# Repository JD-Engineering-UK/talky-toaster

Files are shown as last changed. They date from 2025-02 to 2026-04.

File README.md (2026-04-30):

# Talky-toaster

Inspired by the television show Red Dwarf.

This repository contains the firmware for a real-life version of the talky-toaster using a mmWave presence sensor, an audio amplifier and an ESP32S3 microcontroller.

## Features
- OTA update
- Time aware (NTP sync over WiFi)
- MP3 decompression and playback
- Motion sensor reading (including distance)

## TODO:
- [ ] Telemetry
- [ ] Configuration
- [ ] Silent OTA Update (Boot sounds play after OTA update but I don't want sounds playing out of hours)

## Possible Future Development:
- [ ] LED lights when the toaster is "speaking"
- [ ] Integrate more closely with a toaster. Possibly to detect how well-done the toast is or perhaps to simply have a voice line when the toaster lever is pressed down.
- [ ] Implement "wake word detection" to detect rejections of the toasters offers of grilled bread products and respond accordingly

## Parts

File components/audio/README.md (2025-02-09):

# Audio Driver
Simple audio driver to playback uncompressed PCM audio from read only memory

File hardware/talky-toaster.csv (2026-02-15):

Reference | Qty | Value | DNP | Exclude from BOM | Exclude from Board | Footprint | Datasheet
C1,C6 |  | 2 | 22uF |  |  |  | Capacitor_SMD:C_0603_1608Metric_Pad1.08x0.95mm_HandSolder | ~
C2,C3 |  | 2 | DNF | DNP |  |  | Capacitor_SMD:C_0402_1005Metric_Pad0.74x0.62mm_HandSolder | ~
C4 |  |  | 1 | 4.7uF |  |  |  | Capacitor_SMD:C_0603_1608Metric_Pad1.08x0.95mm_HandSolder | ~
C5 |  |  | 1 | 120pF | DNP |  |  | Capacitor_SMD:C_0402_1005Metric_Pad0.74x0.62mm_HandSolder | ~
C7,C8,C10 | 3 | 100nF |  |  |  | Capacitor_SMD:C_0402_1005Metric_Pad0.74x0.62mm_HandSolder | ~
C9 |  |  | 1 | 10uF |  |  |  | Capacitor_SMD:C_0603_1608Metric_Pad1.08x0.95mm_HandSolder | ~
D1,D2 |  | 2 | D_Schottky_Small |  |  |  | Diode_SMD:D_SOD-123 | ~
D3 |  |  | 1 | LED_ARGB |  |  |  | Auto Lib:19237R6GHBHCA012T | ~
J1 |  |  | 1 | UJ20-C-H-G-MSMT-4-P16-TR |  |  |  | Auto Lib:UJ20CHGMSMT4P16TR | https://www.sameskydevices.com/product/resource/supplyframepdf/uj20-c-h-g-msmt-4-p16-tr.pdf
J2 |  |  | 1 | Wj250A-3.5-2P |  |  |  | talky-toaster:Spring Terminal 2P
J3 |  |  | 1 | mmWave Sensor Socket |  |  |  | Connector_PinSocket_2.54mm:PinSocket_1x05_P2.54mm_Vertical | ~
L1 |  |  | 1 | 1uH |  |  |  | Inductor_SMD:L_1812_4532Metric_Pad1.30x3.40mm_HandSolder | ~
R1,R2 |  | 2 | 0R |  |  |  | Resistor_SMD:R_0402_1005Metric_Pad0.72x0.64mm_HandSolder | ~
R3 |  |  | 1 | 420k |  |  |  | Resistor_SMD:R_0402_1005Metric_Pad0.72x0.64mm_HandSolder | ~
R4 |  |  | 1 | 100k |  |  |  | Resistor_SMD:R_0402_1005Metric_Pad0.72x0.64mm_HandSolder | ~
R5 |  |  | 1 | 499k |  |  |  | Resistor_SMD:R_0402_1005Metric_Pad0.72x0.64mm_HandSolder | ~
R6,R7 |  | 2 | 5.1k |  |  |  | Resistor_SMD:R_0402_1005Metric_Pad0.72x0.64mm_HandSolder | ~
R8 |  |  | 1 | 10k |  |  |  | Resistor_SMD:R_0402_1005Metric_Pad0.72x0.64mm_HandSolder | ~
R9 |  |  | 1 | 560k |  |  |  | Resistor_SMD:R_0402_1005Metric_Pad0.72x0.64mm_HandSolder | ~
R10,R11,R12 | 3 | 2.2k |  |  |  | Resistor_SMD:R_0402_1005Metric_Pad0.72x0.64mm_HandSolder | ~
TP1,TP5 |  | 2 | TestPoint_2Pole |  |  |  | Connector_PinHeader_1.00mm:PinHeader_2x01_P1.00mm_Vertical_SMD | ~
TP2 |  |  | 1 | TestPoint_2Pole |  |  |  | Connector_PinSocket_2.54mm:PinSocket_2x01_P2.54mm_Vertical | ~
TP3,TP4 |  | 2 | TestPoint |  |  |  | TestPoint:TestPoint_Pad_D1.0mm | ~
U1 |  |  | 1 | ESP32-S3-WROOM-1 |  |  |  | RF_Module:ESP32-S3-WROOM-1 | https://www.espressif.com/sites/default/files/documentation/esp32-s3-wroom-1_wroom-1u_datasheet_en.pdf
U2 |  |  | 1 | TPS62A01DRL |  |  |  | Package_TO_SOT_SMD:SOT-563 | https://www.ti.com/lit/gpn/tps62a01
U3 |  |  | 1 | MAX98357A |  |  |  | Package_DFN_QFN:TQFN-16-1EP_3x3mm_P0.5mm_EP1.23x1.23mm_ThermalVias | https://www.analog.com/media/en/technical-documentation/data-sheets/MAX98357A-MAX98357B.pdf

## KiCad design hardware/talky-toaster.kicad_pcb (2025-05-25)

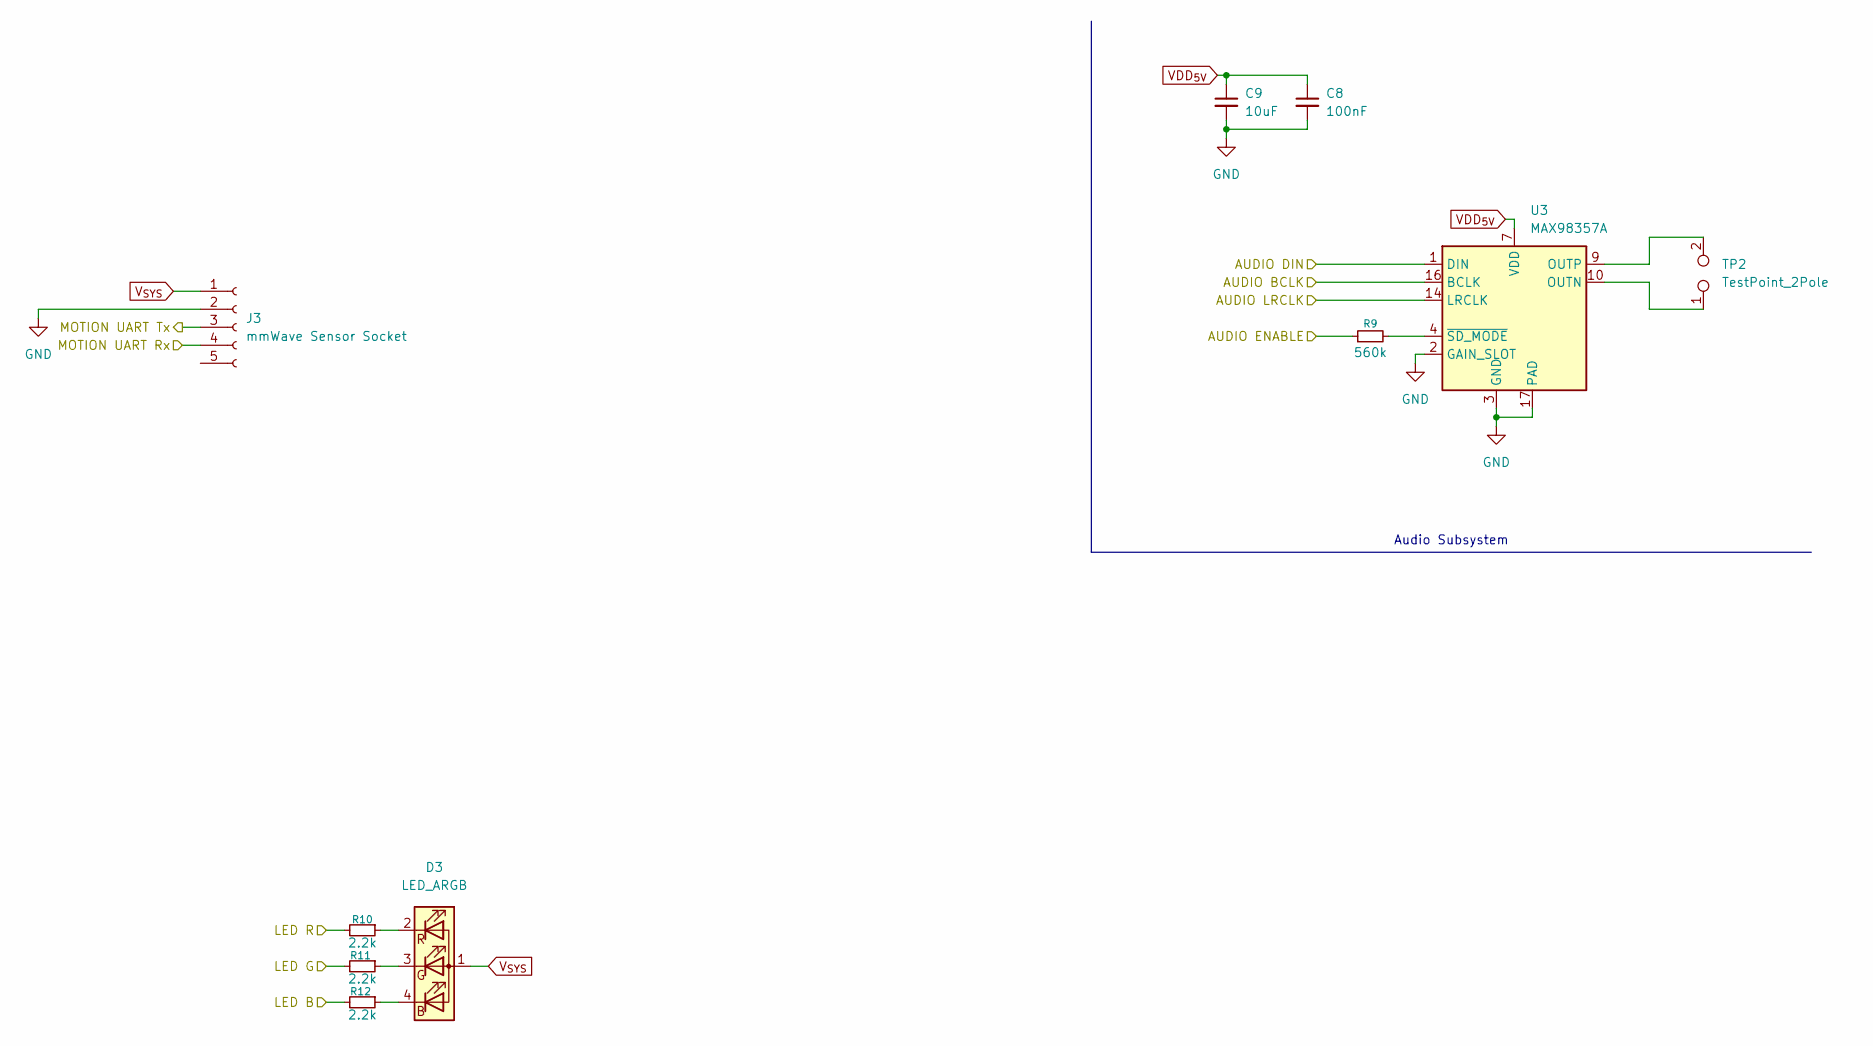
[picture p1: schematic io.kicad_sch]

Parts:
C8: 100nF; C_0402_1005Metric_Pad0.74x0.62mm_HandSolder
C9: 10uF; C_0603_1608Metric_Pad1.08x0.95mm_HandSolder
D3: LED_ARGB; 19237R6GHBHCA012T
J3: mmWave Sensor Socket; PinSocket_1x05_P2.54mm_Vertical
R9: 560k; R_0402_1005Metric_Pad0.72x0.64mm_HandSolder
R10, R11, R12: 2.2k; R_0402_1005Metric_Pad0.72x0.64mm_HandSolder
TP2: TestPoint_2Pole; PinSocket_2x01_P2.54mm_Vertical
U3: MAX98357A; TQFN-16-1EP_3x3mm_P0.5mm_EP1.23x1.23mm_ThermalVias

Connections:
/IO/AUDIO BCLK: U3.16 (BCLK); also elsewhere on the board
/IO/AUDIO DIN: U3.1 (DIN); also elsewhere on the board
/IO/AUDIO ENABLE: R9.1; also elsewhere on the board
/IO/AUDIO LRCLK: U3.14 (LRCLK); also elsewhere on the board
/IO/LED B: R12.2; also elsewhere on the board
/IO/LED G: R11.2; also elsewhere on the board
/IO/LED R: R10.2; also elsewhere on the board
/IO/MOTION UART Rx: J3.4; also elsewhere on the board
/IO/MOTION UART Tx: J3.3; also elsewhere on the board
GND: C8.2, C9.2, J3.2, U3.2 (GAIN_SLOT), U3.3 (GND), U3.11 (GND), U3.15 (GND), U3.17 (PAD); also elsewhere on the board
unnamed: D3.4 (BK), R12.1
unnamed: D3.3 (GK), R11.1
unnamed: D3.2 (RK), R10.1
unnamed: TP2.1, U3.10 (OUTN)
unnamed: TP2.2, U3.9 (OUTP)
unnamed: R9.2, U3.4 (~SD_MODE)
VDD_{5V}: C8.1, C9.1, U3.7 (VDD), U3.8 (VDD); also elsewhere on the board
V_{SYS}: D3.1 (A), J3.1; also elsewhere on the board

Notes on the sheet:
Audio Subsystem

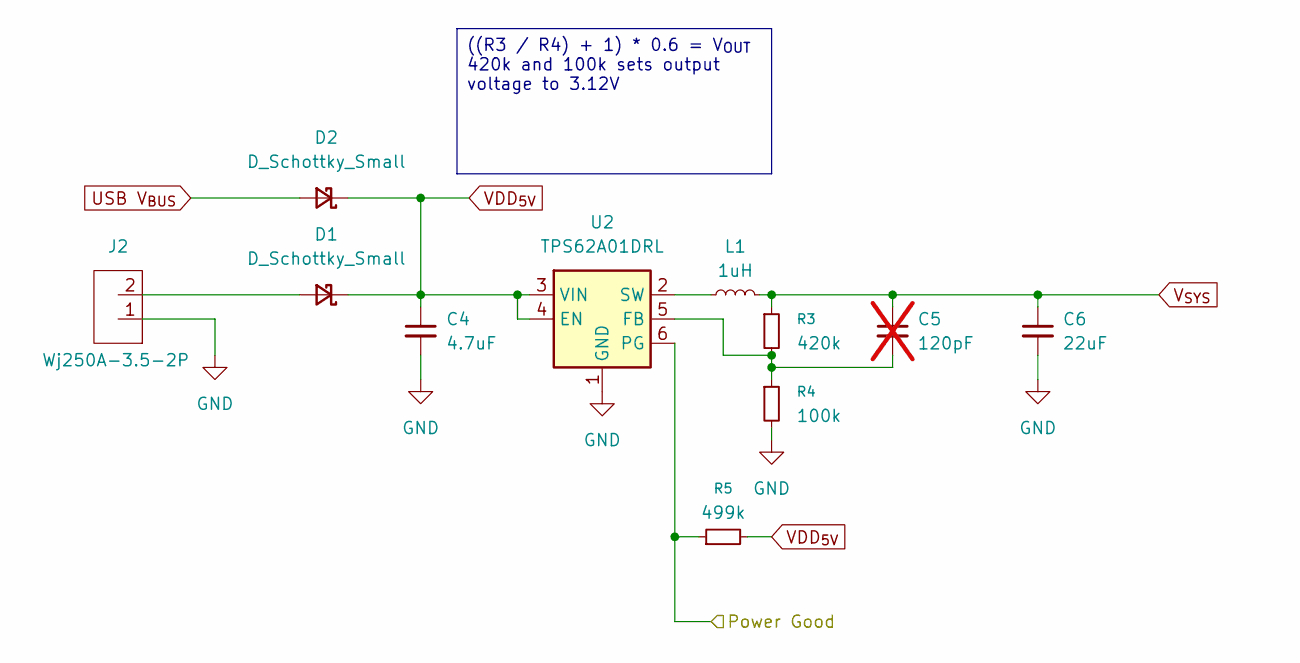
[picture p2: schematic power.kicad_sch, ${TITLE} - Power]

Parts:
C4: 4.7uF; C_0603_1608Metric_Pad1.08x0.95mm_HandSolder
C5: 120pF; C_0402_1005Metric_Pad0.74x0.62mm_HandSolder; not fitted
C6: 22uF; C_0603_1608Metric_Pad1.08x0.95mm_HandSolder
D1, D2: D_Schottky_Small; D_SOD-123
J2: Wj250A-3.5-2P; Spring Terminal 2P
L1: 1uH; L_1812_4532Metric_Pad1.30x3.40mm_HandSolder
R3: 420k; R_0402_1005Metric_Pad0.72x0.64mm_HandSolder
R4: 100k; R_0402_1005Metric_Pad0.72x0.64mm_HandSolder
R5: 499k; R_0402_1005Metric_Pad0.72x0.64mm_HandSolder
U2: TPS62A01DRL; SOT-563

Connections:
/MCU/Power Good: R5.1, U2.6 (PG); also elsewhere on the board
GND: C4.2, C6.2, J2.1, R4.2, U2.1 (GND); also elsewhere on the board
unnamed: D1.2 (A), J2.2
unnamed: C5.2, R3.2, R4.1, U2.5 (FB)
unnamed: L1.1, U2.2 (SW)
USB V_{BUS}: D2.2 (A); also elsewhere on the board
VDD_{5V}: C4.1, D1.1 (K), D2.1 (K), R5.2, U2.3 (VIN), U2.4 (EN); also elsewhere on the board
V_{SYS}: C5.1, C6.1, L1.2, R3.1; also elsewhere on the board

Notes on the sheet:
((R3 / R4) + 1) * 0.6 = V_{OUT} 420k and 100k sets output voltage to 3.12V

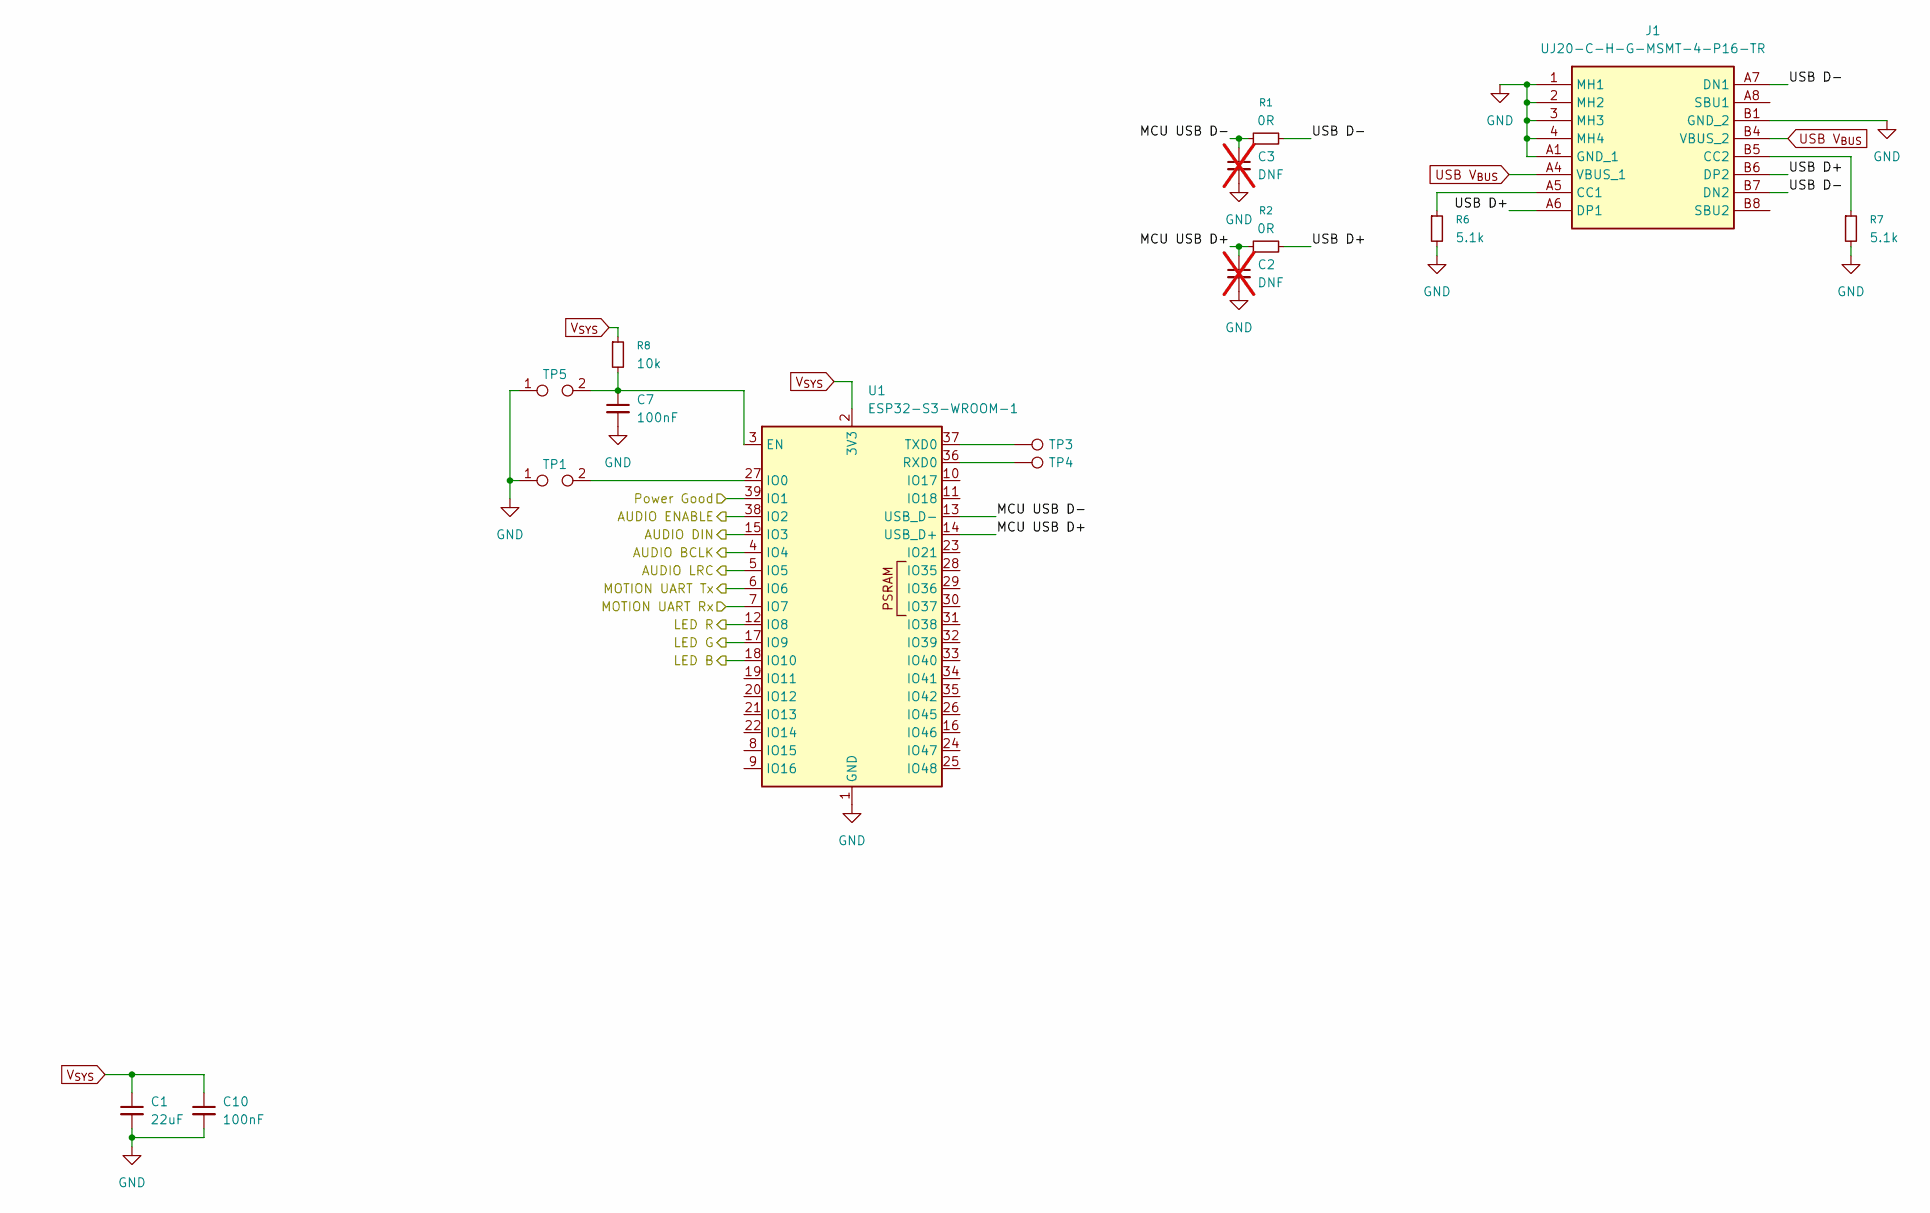
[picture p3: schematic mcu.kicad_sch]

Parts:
C1: 22uF; C_0603_1608Metric_Pad1.08x0.95mm_HandSolder
C2, C3: DNF; C_0402_1005Metric_Pad0.74x0.62mm_HandSolder; not fitted
C7, C10: 100nF; C_0402_1005Metric_Pad0.74x0.62mm_HandSolder
J1: UJ20-C-H-G-MSMT-4-P16-TR; UJ20CHGMSMT4P16TR; Mouser Part Number 179-UJ20CHGMSMT4P16T
R1, R2: 0R; R_0402_1005Metric_Pad0.72x0.64mm_HandSolder
R6, R7: 5.1k; R_0402_1005Metric_Pad0.72x0.64mm_HandSolder
R8: 10k; R_0402_1005Metric_Pad0.72x0.64mm_HandSolder
TP1, TP5: TestPoint_2Pole; PinHeader_2x01_P1.00mm_Vertical_SMD
TP3, TP4: TestPoint; TestPoint_Pad_D1.0mm
U1: ESP32-S3-WROOM-1

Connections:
/IO/AUDIO BCLK: U1.4 (IO4); also elsewhere on the board
/IO/AUDIO DIN: U1.15 (IO3); also elsewhere on the board
/IO/AUDIO ENABLE: U1.38 (IO2); also elsewhere on the board
/IO/AUDIO LRCLK: U1.5 (IO5); also elsewhere on the board
/IO/LED B: U1.18 (IO10); also elsewhere on the board
/IO/LED G: U1.17 (IO9); also elsewhere on the board
/IO/LED R: U1.12 (IO8); also elsewhere on the board
/IO/MOTION UART Rx: U1.6 (IO6); also elsewhere on the board
/IO/MOTION UART Tx: U1.7 (IO7); also elsewhere on the board
/MCU/MCU USB D+: C2.1, R2.1, U1.14 (USB_D+)
/MCU/MCU USB D-: C3.1, R1.1, U1.13 (USB_D-)
/MCU/Power Good: U1.39 (IO1); also elsewhere on the board
/MCU/USB D+: J1.A6 (DP1), J1.B6 (DP2), R2.2
/MCU/USB D-: J1.A7 (DN1), J1.B7 (DN2), R1.2
GND: C1.2, C2.2, C3.2, C7.2, C10.2, J1.1 (MH1), J1.2 (MH2), J1.3 (MH3), J1.4 (MH4), J1.A1 (GND_1), J1.B1 (GND_2), R6.2, R7.2, TP1.1, TP5.1, U1.1 (GND), U1.40 (GND), U1.41 (GND); also elsewhere on the board
unnamed: J1.A5 (CC1), R6.1
unnamed: J1.B5 (CC2), R7.1
unnamed: C7.1, R8.2, TP5.2, U1.3 (EN)
unnamed: TP1.2, U1.27 (IO0)
unnamed: TP4.1, U1.36 (RXD0)
unnamed: TP3.1, U1.37 (TXD0)
USB V_{BUS}: J1.A4 (VBUS_1), J1.B4 (VBUS_2); also elsewhere on the board
V_{SYS}: C1.1, C10.1, R8.1, U1.2 (3V3); also elsewhere on the board

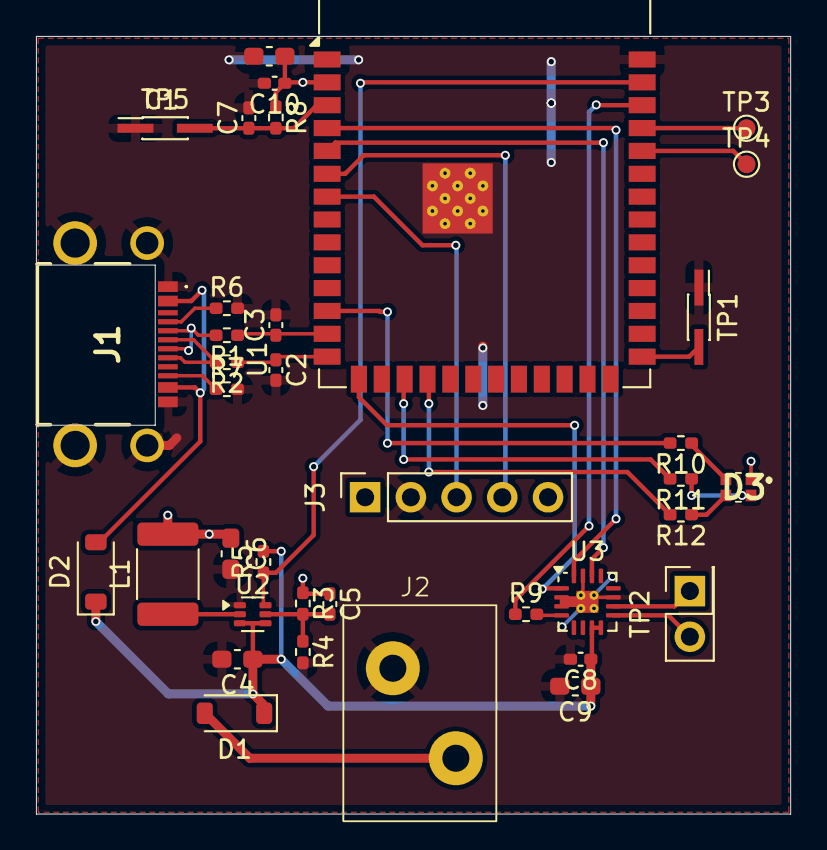
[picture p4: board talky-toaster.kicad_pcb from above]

Board: 2 copper layers, 41.9 x 43.2 mm, 37 parts (0 on the bottom side), 33 nets.

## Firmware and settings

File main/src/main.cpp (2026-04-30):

#include "main.h"
#include "esp_log.h"
#include "esp_timer.h"
#include "freertos/FreeRTOS.h"
#include "freertos/task.h"
#include "esp_chip_info.h"
#include "esp_flash.h"
#include <esp_random.h>
#include "nvs_flash.h"
#include <esp_netif.h>
#include <esp_event.h>
#include <ctime>
#include "esp_system.h"
#include "esp_ota_ops.h"
#include "audio.h"
#include "networking.h"
#include "motionsensor.h"
#include "JD_FOTA.h"

EMBEDDED_FILE(boot_mp3);
EMBEDDED_FILE(howdy_mp3);
EMBEDDED_FILE(im_talkie_mp3);
EMBEDDED_FILE(offer_toast_1_mp3);
EMBEDDED_FILE(offer_toast_2_mp3);
EMBEDDED_FILE(waffle_man_mp3);
static const char *TAG = "Talkie";

static bool previously_detected = false;
static uint32_t detection_time = 0;
static uint32_t last_question_time = 0;
static bool prev_someone_there = false;

extern "C"{
	void app_main();
}


void boot_sequence()
{
    QUEUE_AUDIO(boot_mp3);
    QUEUE_AUDIO(boot_mp3);
    QUEUE_AUDIO(boot_mp3);
    QUEUE_AUDIO(boot_mp3);
    
    QUEUE_AUDIO(howdy_mp3);
    QUEUE_AUDIO(im_talkie_mp3);
    QUEUE_AUDIO(offer_toast_1_mp3);
}

void play_offer(){
	uint32_t num = esp_random();
    switch (num % 3)
    {
        case 0:
            QUEUE_AUDIO(offer_toast_1_mp3);
            break;
        case 1:
            QUEUE_AUDIO(offer_toast_2_mp3);
            break;
        case 2:
            QUEUE_AUDIO(waffle_man_mp3);
            break;
    }
}

void confirm_boot()
{
    const esp_partition_t *running = esp_ota_get_running_partition();
    esp_ota_img_states_t ota_state;
    if (esp_ota_get_state_partition(running, &ota_state) == ESP_OK) 
    {
        if (ota_state == ESP_OTA_IMG_PENDING_VERIFY) 
        {
            esp_ota_mark_app_valid_cancel_rollback();
            ESP_LOGI(TAG, "Boot confirmed, rollback cancelled");
        }
    }
}

bool should_offer_toast()
{
    // Don't ask if we have asked in the last 30 seconds
    if (esp_timer_get_time() - last_question_time < 30000000)
    {
        return false;
    }

    // Don't ask if there is no one there
    if (!motion_sensor_get_detected() || motion_sensor_get_distance() > 75)
    {
        return false;
    }

    // Don't ask if it's night time
    time_t now;
    struct tm timeinfo;
    time(&now);
    localtime_r(&now, &timeinfo);
    if (timeinfo.tm_year > 120 && (timeinfo.tm_hour >= 19 || timeinfo.tm_hour < 8))
    {
        return false;
    }

    // Don't ask if there hasn't been a negative detection of at least 30 seconds
    if (previously_detected && detection_time && (esp_timer_get_time() - detection_time < 30000000))
    {    
        return false;
    }
    
    return true;
}

void do_10_minute_actions()
{
    // Placeholder for any actions we want to do every 10 minutes, such as checking for updates
    start_latest_firmware_update();
    confirm_boot();                 // If we hit here then we can assume the firmware is stable
}

void app_main(void)
{
    //Initialize NVS
    esp_err_t ret = nvs_flash_init();
    if (ret == ESP_ERR_NVS_NO_FREE_PAGES || ret == ESP_ERR_NVS_NEW_VERSION_FOUND) {
      ESP_ERROR_CHECK(nvs_flash_erase());
      ret = nvs_flash_init();
    }
    ESP_ERROR_CHECK(ret);
	ESP_LOGI(TAG, "Flash Initialised");
	ESP_ERROR_CHECK(esp_netif_init());
	ESP_LOGI(TAG, "TCP/IP Stack enabled.");
	ESP_ERROR_CHECK( esp_event_loop_create_default() );
	Wifi *wifi = Wifi::getInstance();
	ESP_ERROR_CHECK(esp_netif_init());

    audio_init();
    setup_motion_sensor();

    boot_sequence();
    vTaskDelay(20000 / portTICK_PERIOD_MS);
    wifi->init();
    // wifi->add_ap("SSID", "password");
    wifi->start();

    uint32_t last_10_minute_action = 0;
    confirm_boot();
    while(1)
    {
        bool current_detected = motion_sensor_get_detected();
        uint16_t current_distance = motion_sensor_get_distance();
        bool current_someone_there = current_detected && (current_distance <= 75);
        
        if (!current_someone_there && prev_someone_there) {
            detection_time = esp_timer_get_time();
            previously_detected = true;
        }
        prev_someone_there = current_someone_there;

        if (should_offer_toast())
        {
            play_offer();
            last_question_time = esp_timer_get_time();
        }

        if (esp_timer_get_time() - last_10_minute_action > 600000000) // 10 minutes
        {
            do_10_minute_actions();
            last_10_minute_action = esp_timer_get_time();
        }

        vTaskDelay( pdMS_TO_TICKS(500) );
    }
    vTaskDelay(portMAX_DELAY);
    fflush(stdout);
    esp_restart();
}

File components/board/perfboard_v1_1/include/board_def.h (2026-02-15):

/*
 * ESPRESSIF MIT License
 *
 * Copyright (c) 2020 <ESPRESSIF SYSTEMS (SHANGHAI) CO., LTD>
 *
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
 */

#ifndef _AUDIO_BOARD_DEFINITION_H_
#define _AUDIO_BOARD_DEFINITION_H_

#define BUTTON_VOLUP_ID           -1     /* You need to define the GPIO pins of your board */
#define BUTTON_VOLDOWN_ID         -1     /* You need to define the GPIO pins of your board */
#define BUTTON_MUTE_ID            -1     /* You need to define the GPIO pins of your board */
#define BUTTON_SET_ID             -1     /* You need to define the GPIO pins of your board */
#define BUTTON_MODE_ID            -1     /* You need to define the GPIO pins of your board */
#define BUTTON_PLAY_ID            -1     /* You need to define the GPIO pins of your board */
#define PA_ENABLE_GPIO            -1     /* You need to define the GPIO pins of your board */
#define ADC_DETECT_GPIO           -1     /* You need to define the GPIO pins of your board */
#define BATTERY_DETECT_GPIO       -1     /* You need to define the GPIO pins of your board */
#define SDCARD_INTR_GPIO          -1     /* You need to define the GPIO pins of your board */

#define SDCARD_OPEN_FILE_NUM_MAX  5

#define BOARD_PA_GAIN             (10) /* Power amplifier gain defined by board (dB) */

#define SDCARD_PWR_CTRL             -1
#define ESP_SD_PIN_CLK              -1
#define ESP_SD_PIN_CMD              -1
#define ESP_SD_PIN_D0               -1
#define ESP_SD_PIN_D1               -1
#define ESP_SD_PIN_D2               -1
#define ESP_SD_PIN_D3               -1
#define ESP_SD_PIN_D4               -1
#define ESP_SD_PIN_D5               -1
#define ESP_SD_PIN_D6               -1
#define ESP_SD_PIN_D7               -1
#define ESP_SD_PIN_CD               -1
#define ESP_SD_PIN_WP               -1

#define RADAR_TX_PIN                GPIO_NUM_11
#define RADAR_RX_PIN                GPIO_NUM_12

extern audio_hal_func_t AUDIO_NEW_CODEC_DEFAULT_HANDLE;

#define AUDIO_CODEC_DEFAULT_CONFIG(){                   \
        .adc_input  = AUDIO_HAL_ADC_INPUT_LINE1,        \
        .dac_output = AUDIO_HAL_DAC_OUTPUT_ALL,         \
        .codec_mode = AUDIO_HAL_CODEC_MODE_BOTH,        \
        .i2s_iface = {                                  \
            .mode = AUDIO_HAL_MODE_SLAVE,               \
            .fmt = AUDIO_HAL_I2S_NORMAL,                \
            .samples = AUDIO_HAL_48K_SAMPLES,           \
            .bits = AUDIO_HAL_BIT_LENGTH_16BITS,        \
        },                                              \
};

#define INPUT_KEY_NUM     0             /* You need to define the number of input buttons on your board */

#define INPUT_KEY_DEFAULT_INFO() {}

#endif

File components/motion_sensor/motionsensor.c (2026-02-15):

#include "include/motionsensor.h"

#include <stdio.h>
#include <string.h>

#include "esp_log.h"
#include "include/module.h"
#include "include/timing.h"
#include "include/report.h"
#include "freertos/semphr.h"


#define UART_PORT (uart_port_t) CONFIG_MOTION_SENSOR_UART_NUM

static bool uart_initialised = false;
static TaskHandle_t* motion_sensor_task_handle;

static motion_sensor_state_t motion_sensor_state = STATE_UNKNOWN;
static TickType_t last_received = 0;
static report_t* report;
static SemaphoreHandle_t mutex = NULL;


uint16_t motion_sensor_get_distance(){
    if(mutex == NULL || report == NULL) return 0;
    uint16_t result;
    xSemaphoreTake(mutex, portMAX_DELAY);
    result = report->distance;
    xSemaphoreGive(mutex);
    return result;
}

bool motion_sensor_get_detected(){
    if(mutex == NULL || report == NULL) return false;
    bool result;
    xSemaphoreTake(mutex, portMAX_DELAY);
    result = report->detected;
    xSemaphoreGive(mutex);
    return result;
}


esp_err_t send_command(uint16_t command_code, uint8_t* command_data,
                       uint16_t command_data_length) {
    uint16_t len = 2 + command_data_length;
    uint8_t buff[10 + len];

    memcpy(buff, COMMAND_HEADER, 4);
    buff[4] = len & 0xFF;
    buff[5] = len >> 8;
    buff[6] = command_code & 0xFF;
    buff[7] = command_code >> 8;
    if (command_data != NULL && command_data_length != 0) {
        memcpy(buff + 8, command_data, command_data_length);
    }
    memcpy(buff + 8 + command_data_length, COMMAND_FOOTER, 4);

    return uart_write_bytes(UART_PORT, buff, 10 + len);
}

esp_err_t set_mode_report() {
    const uint16_t command_code = 0x0012;
    const uint8_t* data = (uint8_t[]){0x00, 0x00, 0x04, 0x00, 0x00, 0x00};
    return send_command(command_code, data, 6);
}

void read_uart(uint8_t* buffer, int* buffer_len, const int max_buf_len,
               TickType_t delay) {
    int len = uart_read_bytes(UART_PORT, buffer + *buffer_len,
                                   max_buf_len - *buffer_len, delay);
    *buffer_len += len;
    if(len > 0) init_timer(&last_received);
}

bool is_report_mode(uint8_t* buffer, int buffer_len) {
    for (int i = 0; i < buffer_len - 4; ++i) {
        if (memcmp(buffer + i, REPORT_HEADER, 4) == 0) return true;
    }
    return false;
}

int find_report_start(uint8_t* buffer, int buffer_len){
    for (int i = 0; i < buffer_len - 4; ++i) {
        if (memcmp(buffer + i, REPORT_HEADER, 4) == 0) return i;
    }
    return -1;
}

bool is_normal_mode(uint8_t* buffer, int buffer_len) {
    for (int i = 0; i < buffer_len - 5; ++i) {
        if (memcmp(buffer + i, "Range", 5) == 0) return true;
    }
    return false;
}



void motion_sensor_task(void* args) {
    uint8_t* buffer = (uint8_t*)malloc(64);
    report = allocate_report();
    bool report_updated = false;
    int buffer_len = 0;
    TickType_t timer = 0;
    int report_offset = -1;
    uint16_t len;
    while (1) {
        read_uart(buffer, &buffer_len, 64, 100 / portTICK_PERIOD_MS);
        report_updated = false;

        switch (motion_sensor_state) {
            case STATE_CONFIGURE:
                if (is_report_mode(buffer, buffer_len)) {
                    motion_sensor_state = STATE_RUNNING;
                    ESP_LOGI(TAG, "Motion sensor configured.");
                    break;
                }
                if (get_timeout(&timer, 500) &&
                    is_normal_mode(buffer, buffer_len)) {
                    ESP_LOGD(
                        TAG,
                        "Motion sensor in normal mode. Setting report mode...");
                    set_mode_report();
                    init_timer(&timer);
                } else if (get_timeout(&timer, 5000)) {
                    ESP_LOGD(TAG, "No mode detected. Setting report mode...");
                    set_mode_report();
                    init_timer(&timer);
                }

                buffer_len = 0;
                break;

            case STATE_RUNNING:
                if(get_timeout(&last_received, 5000)){
                    buffer_len = 0;
                    motion_sensor_state = STATE_CONFIGURE;
                    break;
                }

                // Find the header of the packet in the buffer.
                report_offset = find_report_start(buffer, buffer_len);
                if(report_offset < 0 && buffer_len > 4){
                    // When we don't find the report in the buffer
                    // Discard almost all of the buffer
                    memmove(buffer, buffer+buffer_len-4, 4);
                    buffer_len = 4;
                    break;
                }else if (report_offset < 0)
                {
                    break;
                }
                
                // Found the start of the report
                if(buffer_len-report_offset < 45){
                    // Report length is fixed at 45 bytes.
                    // Discard start of buffer before the report if we don't have the full report in the buffer.
                    memmove(buffer, buffer+report_offset, buffer_len-report_offset);
                    buffer_len -= report_offset;
                    report_offset = -1;
                    break;
                }

                xSemaphoreTake(mutex, portMAX_DELAY);
                parse_report(buffer+report_offset, buffer_len-report_offset, report);
                xSemaphoreGive(mutex);
                report_updated = true;
                if(buffer_len <= 45) buffer_len = 0;
                else{
                    memmove(buffer, buffer+report_offset+45, buffer_len-report_offset-45);
                    buffer_len -= report_offset + 45;
                        report_offset = -1;
                }
                
                break;

            default:
                vTaskDelay(100 / portTICK_PERIOD_MS);
                buffer_len = 0;
                break;
        }

        // if(report_updated)
        // {
        //     ESP_LOGI(TAG, "Detected: %02d, Distance: %02d", report->detected, report->distance);
        //     ESP_LOGI(TAG, "GATES: %02d %02d %02d %02d %02d %02d %02d %02d %02d %02d %02d %02d %02d %02d %02d %02d", report->gate_energies[0], report->gate_energies[1], report->gate_energies[2], report->gate_energies[3], report->gate_energies[4], report->gate_energies[5], report->gate_energies[6], report->gate_energies[7], report->gate_energies[8], report->gate_energies[9], report->gate_energies[10], report->gate_energies[11], report->gate_energies[12], report->gate_energies[13], report->gate_energies[14], report->gate_energies[15]);
        // }
        
    }
    free(buffer);
    deallocate_report(report);
}
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

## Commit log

2025-02-08 Update readme Found out how to configure the sensor
2025-02-09 Add introduction
    New problem: run out of flash memory...
    [main.c]
2025-02-22 Dev board I'm using has 8MB of additional RAM that wasn't enabled
2025-05-17 WiFi Working with SNTP. Boot audio bugs out
    [main.cpp]
2025-05-25 Surviving design files...
    I messed up git and fork. Most of the files are gone. This is what I could recover.
    [io.kicad_sch, mcu.kicad_sch, power.kicad_sch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]
2026-02-15 New WiFi component. Enable motion sensor handling. Play audio when motion detected.
    [partitions.csv, talky-toaster.csv]
